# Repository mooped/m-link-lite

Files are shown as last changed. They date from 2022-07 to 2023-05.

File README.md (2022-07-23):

# M-Link Lite

M-Link Lite is a receiver for combat robotics based on the ESP8266 microcontroller. It acts as a WiFi access point and can be controlled from a WebSocket.

M-Link Lite hosts a web server with a basic page for controlling a simple combat robot.

Additional files can be uploaded to control more complex robots with up to 6 channels.

The servo pulsewidth data sent to the WebSocket is passed straight through to the outputs to avoid limiting possibilities.

M-Link Lite has a configurable failsafe so if no updates are received for 500ms the outputs will be put into a safe state.

When turned on M-Link will create a WiFi Access Point named m-link-XXXXXX where XXXXXX is a unique set of digits that identifies the device. The device should be labelled with this ID. A single user can connect to this access point and the controller page should be accessible by navigating to http://m-link-XXXXXXX.local or if wildcard DNS is enabled to any url e.g. http://m-link/ .

When connected to the access point the device will always be available at http://192.168.4.1 . If you are having trouble when using the access point from a mobile device, turning off mobile internet so WiFi is the only option may help.

Once configured via the access point you can enter details for your own access point and the device will connect to it from then on.

## Extending M-Link Lite

The default Drive page on the M-Link Lite device provides a single virtual joystick that directly drives the first two channels. It performs no mixing and is designed for a dual ESC with onboard mixing.

If you wish to use all 6 channels or other features you can upload additional files through the File Manager page that make use of these features.

As a starting point it is recommended to download the default 'Drive' page from [main/joystick.html](main/joystick.html), modify it. You can use the File Manager page on the device to upload and test the modified version.

The on-screen Joystick is implemented with [jeromeetienne/virtualjoystick.js](https://github.com/jeromeetienne/virtualjoystick.js) which has its own documentation and examples for adding additional joysticks.

Some examples are provided for implementing [one](examples/joystick.html), [two](examples/two_stick.html), or [three](examples/three_stick.html) on-screen joysticks in the [examples folder](examples) of the project.

The page talks to the M-Link Lite by sending JSON messages over a websocket and the device will send JSON messages back in response.

The code at line 40 of the Drive page sends an initial packet to center all outputs, and it also sends a set of failsafe values which will be applied if a packet is not received for 500 milliseconds. This is intended to avoid the robot going out of control if the user closes their browser, turns of the controlling device, or the connection is otherwise disrupted.

```
        ws.onopen = function() {
          ws.send(
            JSON.stringify(
              {
                servos: [
                  1500,
                  1500,
                  1500,
                  1500,
                  1500,
                  1500
                ],
                failsafes: [
                  1500,
                  1500,
                  1500,
                  1500,
                  1500,
                  1500
                ],
                query: "settings"
              }
            )
          );
        };
```

The default failsafes will stop a brushed ESC that has a reverse feature and center a servo. If you intend to build a robot using non-reversible ESCs or your servo driven mechanisms require a different position on failsafe you will need to update these values.

The values sent in the `servos` and `failsafes` array are the pulse width that will be sent to the servo in microseconds. 1000 microseconds is usually fully left, 2000 microseconds is fully right, and 1500 microseconds is centered. You can send 0 microseconds to stop sending a signal, which will cause many servos to idle, but depending on the servos you will need to be careful with other out of range values which may cause unexpected behaviour and/or damage.

For the `failsafes` array a value of -1 can be set instead of a pulsewidth to hold the channel at its last position when in failsafe.

The code between lines 103 and 124 is responsible for sending updated values to the M-Link Lite 30 times a second. By altering the values to the `servos` array you can make use of all 6 channels.

```
      setInterval(function(){
        const x = Math.round(joystick.deltaX() * 5);
        const y = Math.round(joystick.deltaY() * 5);
        $msg = JSON.stringify({
          servos: [
            parseInt(1500 - y),
            parseInt(1500 + x),
            1500,
            1500,
            1500,
            1500,
          ]
        });
        if ($('#send').val() != $msg || (++counter % keepalive) === 0) {
          $('#send').val($msg);
          ws.send($msg);
        }

        var outputEl  = document.getElementById('result');
        outputEl.innerHTML = $('#wsresponse').val();

      }, 1/30 * 1000);
```

For example you could declare a second VirtualJoystick instance and have it respond to a second area of the screen, and use it to drive 1 or 2 of the extra channels.

These extensions are likely to depend on the intended features of the robot so the system has designed to leave these up to the user while providing maximum flexibility.

For ease of experimentation the default Drive page declares a `mlink` object in the global scope which contains a reference to the WebSocket. You can use this from the browser's Javascript console to send messages manually.

For example, to request the M-Link device send back the current battery voltage reading:

```
mlink.ws.send(JSON.stringify({
  query: "battery"
});
```

## WebSocket API

The WebSocket API expects a JSON message and responds based on the keys contained in the message.

### Sending servo pulsewidths to drive the robot:

For example Ch 1 center/brake, Ch 2 left/reverse, Ch 3 right/forward, Ch 4 center/brake, Ch 5 left/reverse, Ch 6 right/forward

```
{
  servos: [
    1500,
    1000,
    2000,
    1500,
    1000,
    2000
  ]
}
```

The M-Link will read as many channels from the array as it supports and then ignore any additional values. If fewer values are sent than are supported the remaining channels will be left alone.

### Setting Failsafe Positions

For example Ch 1 center/brake, Ch2 left, Ch3 right, Ch4/5/6 hold position

```
{
  failsafes: [
    1500,
    1000,
    2000,
    -1
    -1
    -1
  ]
}
```

The `failsafes` key is handled in the same way as a `servos` key with the exception that -1 is interpreted as hold position.

### Updating settings

```
{
  settings: {
    name: "My Robot",
    ssid: "my-ssid",
    password: "my-password"
  }
}
```

The settings object can contain any or all of the keys `name`, `ssid`, `password` and the settings relating to any keys provided will be updated upon receipt of the packet.

If the SSID or Password for the WiFi are changed the settings will be saved immediately but the device must be rebooted before they will take effect.

The SSID and Password fields refer to an external Access Point the device will try to connect to. The details for the M-Link's Access Point are fixed and cannot be changed.

### Resetting Settings

```
{
  reset_settings: "sgnittes_teser"
}
```

The `reset_settings` key will cause a reset of all settings to factory defaults as soon as it is received, so long as the value is the string `"reset_settings"` backwards to prevent accidental resets.

### Rebooting

```
{
  reboot: "toober"
}
```

The `reboot` key will cause an immediate reboot of the device so long as the value is the string `"reboot"` backwards, to prevent accidental reboots.

This can be used after updating settings to apply any that require a reboot to take effect.

### Query

The query key can be used to read various values back from the M-Link.

```
{
  query: "battery"
}
```

The device will respond to a `battery` query with an object containing the value read on the ADC which may be connected to an external battery of the 5v rail of the servo connectors depending on the device and how it is wired.

```
{
  query: "failsafes"
}
```

The device will respond to a `failsafes` query with the current failsafe values.

```
{
  query: "settings"
}
```

The device will respond to a `settings` query with an object containing the current settings.

## Safety

M-Link Lite is designed as a simple device to make it easy to get started and because of this it has been designed to be simple and robust at the expense of some security features.

To avoid users locking themselves out of the device its Access Point has a fixed password, and when connected to a shared Access Point there is no authentication to prevent other users from taking control of the device. For this reason we do not recommend using this device for any robot with spinning weapons or any other weapons that would be dangerous if activated unexpectedly.

## Building The Project

This project is based on the ESP8266 FreeRTOS SDK, which is the ESP8266 equivalent of the ESP32's ESP-IDF project.

You can find instructions for installing and setting this up in their [Getting Started Guide](https://docs.espressif.com/projects/esp8266-rtos-sdk/en/latest/get-started/index.html).

This project uses a version of the ESP8266 FreeRTOS SDK that I modified to include the ESP32 version's web server. You will need to check out [my ESP8266_RTOS_SDK_ESP32TTTPD project](https://github.com/mooped/ESP8266_RTOS_SDK_ESP32HTTPD) instead of the official version.

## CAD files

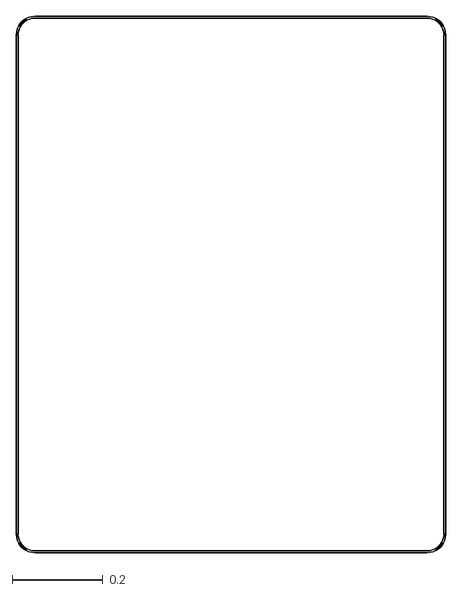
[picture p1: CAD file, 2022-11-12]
hardware/m-link-lite_v1_1_stencil/m-link-lite-Edge_Cuts.dxf
0.949 x 1.19

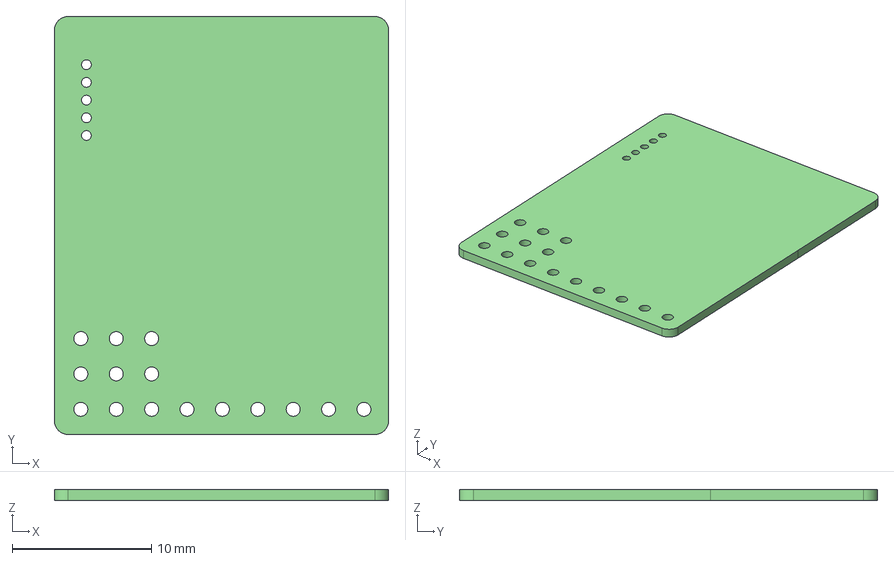
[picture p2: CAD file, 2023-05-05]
hardware_plus/m-link-plus.step
24.0 x 30.0 x 0.791 mm

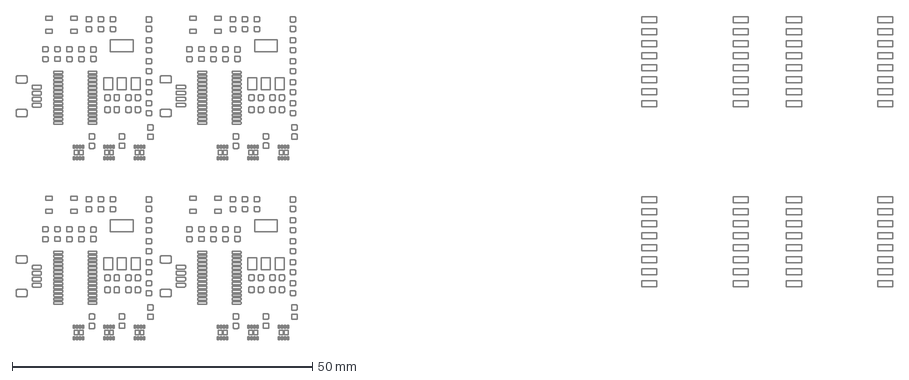
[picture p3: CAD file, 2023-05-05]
hardware_plus/m-link-plus_v1_0_stencil/merged_2x2.dxf
146.1 x 53.9 mm

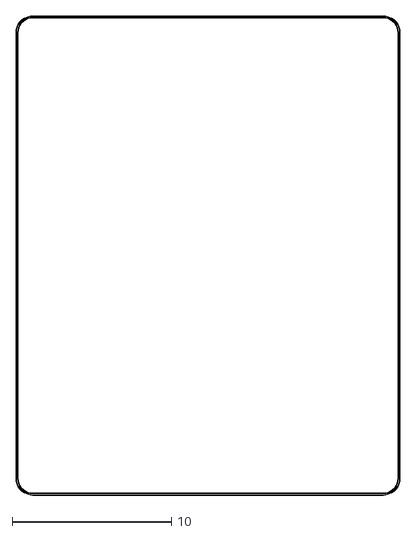
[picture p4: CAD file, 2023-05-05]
hardware_plus/m-link-plus_v1_0_stencil/m-link-plus-Edge_Cuts.dxf
24.1 x 30.1

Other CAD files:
hardware/m-link-lite_v1_1_stencil/m-link-lite-B_Paste.dxf
hardware/m-link-lite_v1_1_stencil/m-link-lite-F_Paste.dxf
hardware_plus/m-link-plus_v1_0_stencil/m-link-plus-B_Paste.dxf
hardware_plus/m-link-plus_v1_0_stencil/m-link-plus-F_Paste.dxf

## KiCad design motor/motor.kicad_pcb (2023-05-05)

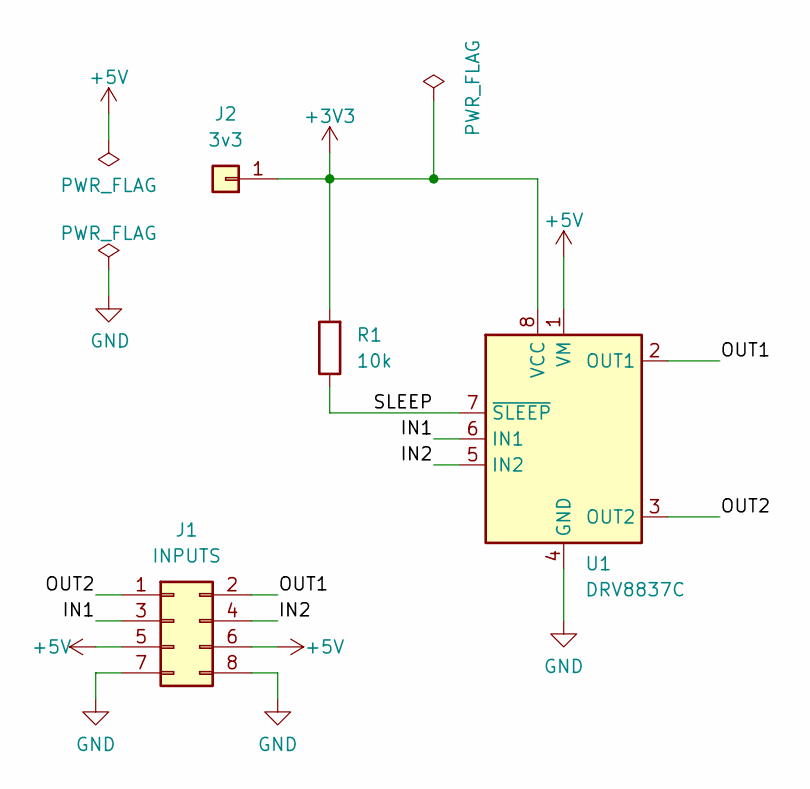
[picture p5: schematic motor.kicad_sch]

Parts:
J1: INPUTS; PinHeader_2x04_P2.54mm_Vertical
J2: 3v3; PinHeader_1x01_P2.54mm_Vertical
R1: 10k; R_0603_1608Metric
U1: DRV8837C; WSON-8-1EP_2x2mm_P0.5mm_EP0.9x1.6mm

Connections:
+3V3: J2.1, R1.2, U1.8 (VCC)
+5V: J1.5, J1.6, U1.1 (VM)
/IN1: J1.3, U1.6 (IN1)
/IN2: J1.4, U1.5 (IN2)
/OUT1: J1.2, U1.2 (OUT1)
/OUT2: J1.1, U1.3 (OUT2)
/SLEEP: R1.1, U1.7 (~SLEEP)
GND: J1.7, J1.8, U1.4 (GND), U1.9 (GND)

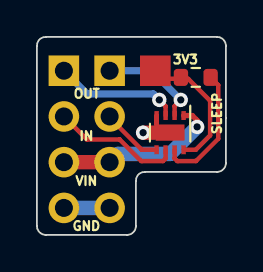
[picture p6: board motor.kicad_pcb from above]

Board: 2 copper layers, 10.5 x 11.0 mm, 4 parts (0 on the bottom side), 8 nets.

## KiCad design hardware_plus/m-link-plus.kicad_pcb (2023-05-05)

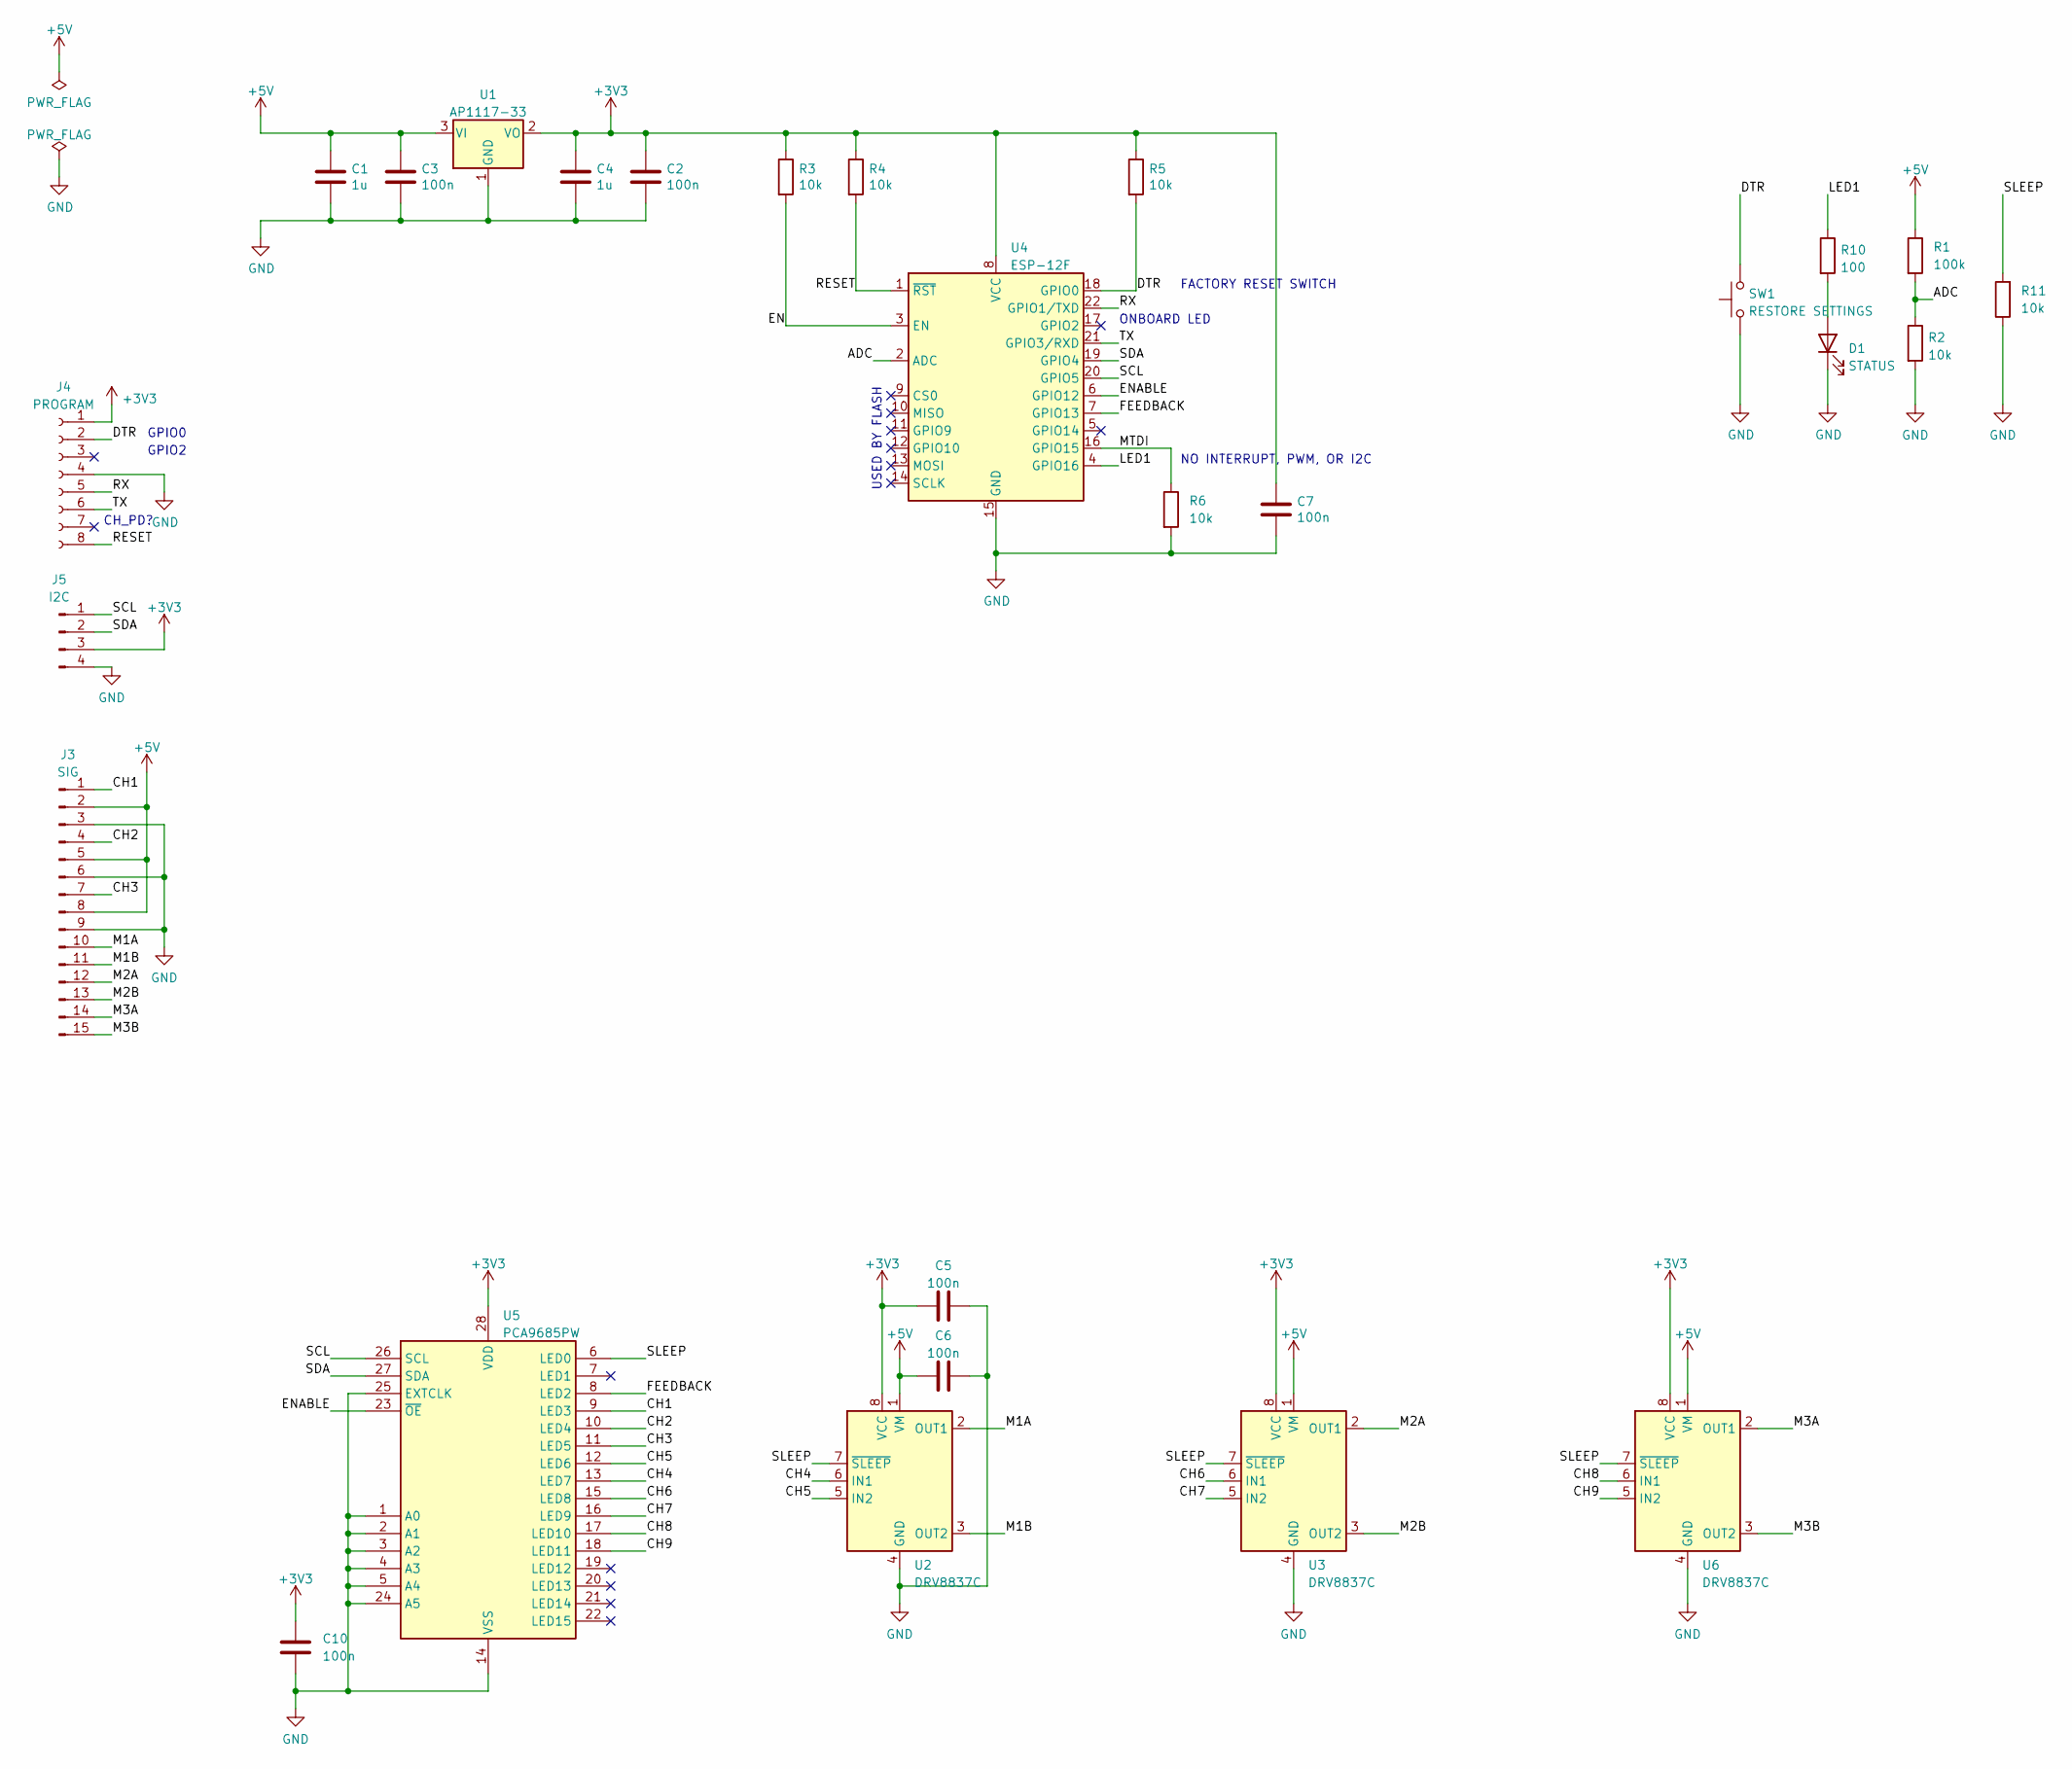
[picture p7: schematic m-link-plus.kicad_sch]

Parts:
C1, C4: 1u; C_0603_1608Metric
C2, C3, C5, C6, C7, C10: 100n; C_0603_1608Metric
D1: STATUS; LED_0603_1608Metric
J3: SIG; ServoHeader_3x06_P2.54mm_Vertical
J4: PROGRAM; SOIC_clipProgSmall
J5: I2C; JST_SH_BM04B-SRSS-TB_1x04-1MP_P1.00mm_Vertical
R1: 100k; R_0603_1608Metric
R2, R3, R4, R5, R6, R11: 10k; R_0603_1608Metric
R10: 100; R_0603_1608Metric
SW1: RESTORE SETTINGS; SW_SPST_PTS810
U1: AP1117-33; SOT-223-3_TabPin2
U2, U3, U6: DRV8837C; WSON-8-1EP_2x2mm_P0.5mm_EP0.9x1.6mm
U4: ESP-12F; ESP-12E
U5: PCA9685PW; TSSOP-28_4.4x9.7mm_P0.65mm

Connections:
+3V3: C2.1, C4.1, C5.1, C7.1, C10.1, J4.1, J5.3, R3.1, R4.1, R5.1, U1.2 (VO), U2.8 (VCC), U3.8 (VCC), U4.8 (VCC), U5.28 (VDD), U6.8 (VCC)
+5V: C1.1, C3.1, C6.1, J3.2, J3.5, J3.8, R1.1, U1.3 (VI), U2.1 (VM), U3.1 (VM), U6.1 (VM)
/ADC: R1.2, R2.1, U4.2 (ADC)
/CH1: J3.1, U5.9 (LED3)
/CH2: J3.4, U5.10 (LED4)
/CH3: J3.7, U5.11 (LED5)
/CH4: U2.6 (IN1), U5.13 (LED7)
/CH5: U2.5 (IN2), U5.12 (LED6)
/CH6: U3.6 (IN1), U5.15 (LED8)
/CH7: U3.5 (IN2), U5.16 (LED9)
/CH8: U5.17 (LED10), U6.6 (IN1)
/CH9: U5.18 (LED11), U6.5 (IN2)
/DTR: J4.2, R5.2, SW1.2, U4.18 (GPIO0)
/EN: R3.2, U4.3 (EN)
/ENABLE: U4.6 (GPIO12), U5.23 (~OE)
/FEEDBACK: U4.7 (GPIO13), U5.8 (LED2)
/LED1: R10.1, U4.4 (GPIO16)
/M1A: J3.10, U2.2 (OUT1)
/M1B: J3.11, U2.3 (OUT2)
/M2A: J3.12, U3.2 (OUT1)
/M2B: J3.13, U3.3 (OUT2)
/M3A: J3.14, U6.2 (OUT1)
/M3B: J3.15, U6.3 (OUT2)
/MTDI: R6.1, U4.16 (GPIO15)
/RESET: J4.8, R4.2, U4.1 (~RST)
/RX: J4.5, U4.22 (GPIO1/TXD)
/SCL: J5.1, U4.20 (GPIO5), U5.26 (SCL)
/SDA: J5.2, U4.19 (GPIO4), U5.27 (SDA)
/SLEEP: R11.2, U2.7 (~SLEEP), U3.7 (~SLEEP), U5.6 (LED0), U6.7 (~SLEEP)
/TX: J4.6, U4.21 (GPIO3/RXD)
GND: C1.2, C2.2, C3.2, C4.2, C5.2, C6.2, C7.2, C10.2, D1.1 (K), J3.3, J3.6, J3.9, J4.4, J5.4, R2.2, R6.2, R11.1, SW1.1, U1.1 (GND), U2.4 (GND), U2.9 (GND), U3.4 (GND), U3.9 (GND), U4.15 (GND), U5.1 (A0), U5.2 (A1), U5.3 (A2), U5.4 (A3), U5.5 (A4), U5.14 (VSS), U5.24 (A5), U5.25 (EXTCLK), U6.4 (GND), U6.9 (GND)
unnamed: D1.2 (A), R10.2

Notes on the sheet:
FACTORY RESET SWITCH
GPIO0
NO INTERRUPT, PWM, OR I2C
CH_PD?
USED BY FLASH
GPIO2
ONBOARD LED

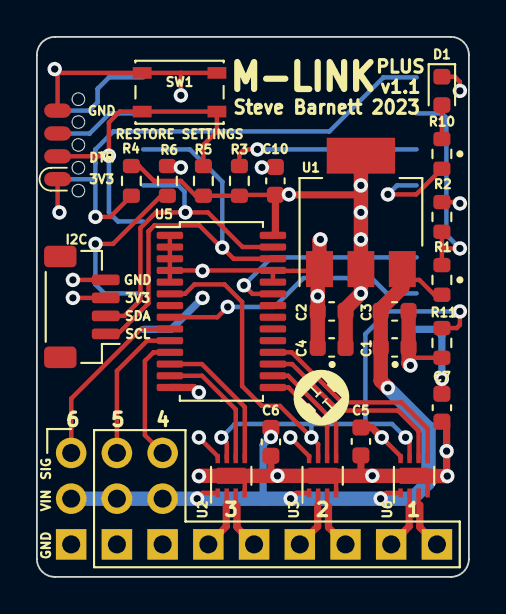
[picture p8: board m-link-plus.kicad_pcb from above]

Board: 4 copper layers, 24.0 x 30.0 mm, 27 parts (1 on the bottom side), 32 nets.

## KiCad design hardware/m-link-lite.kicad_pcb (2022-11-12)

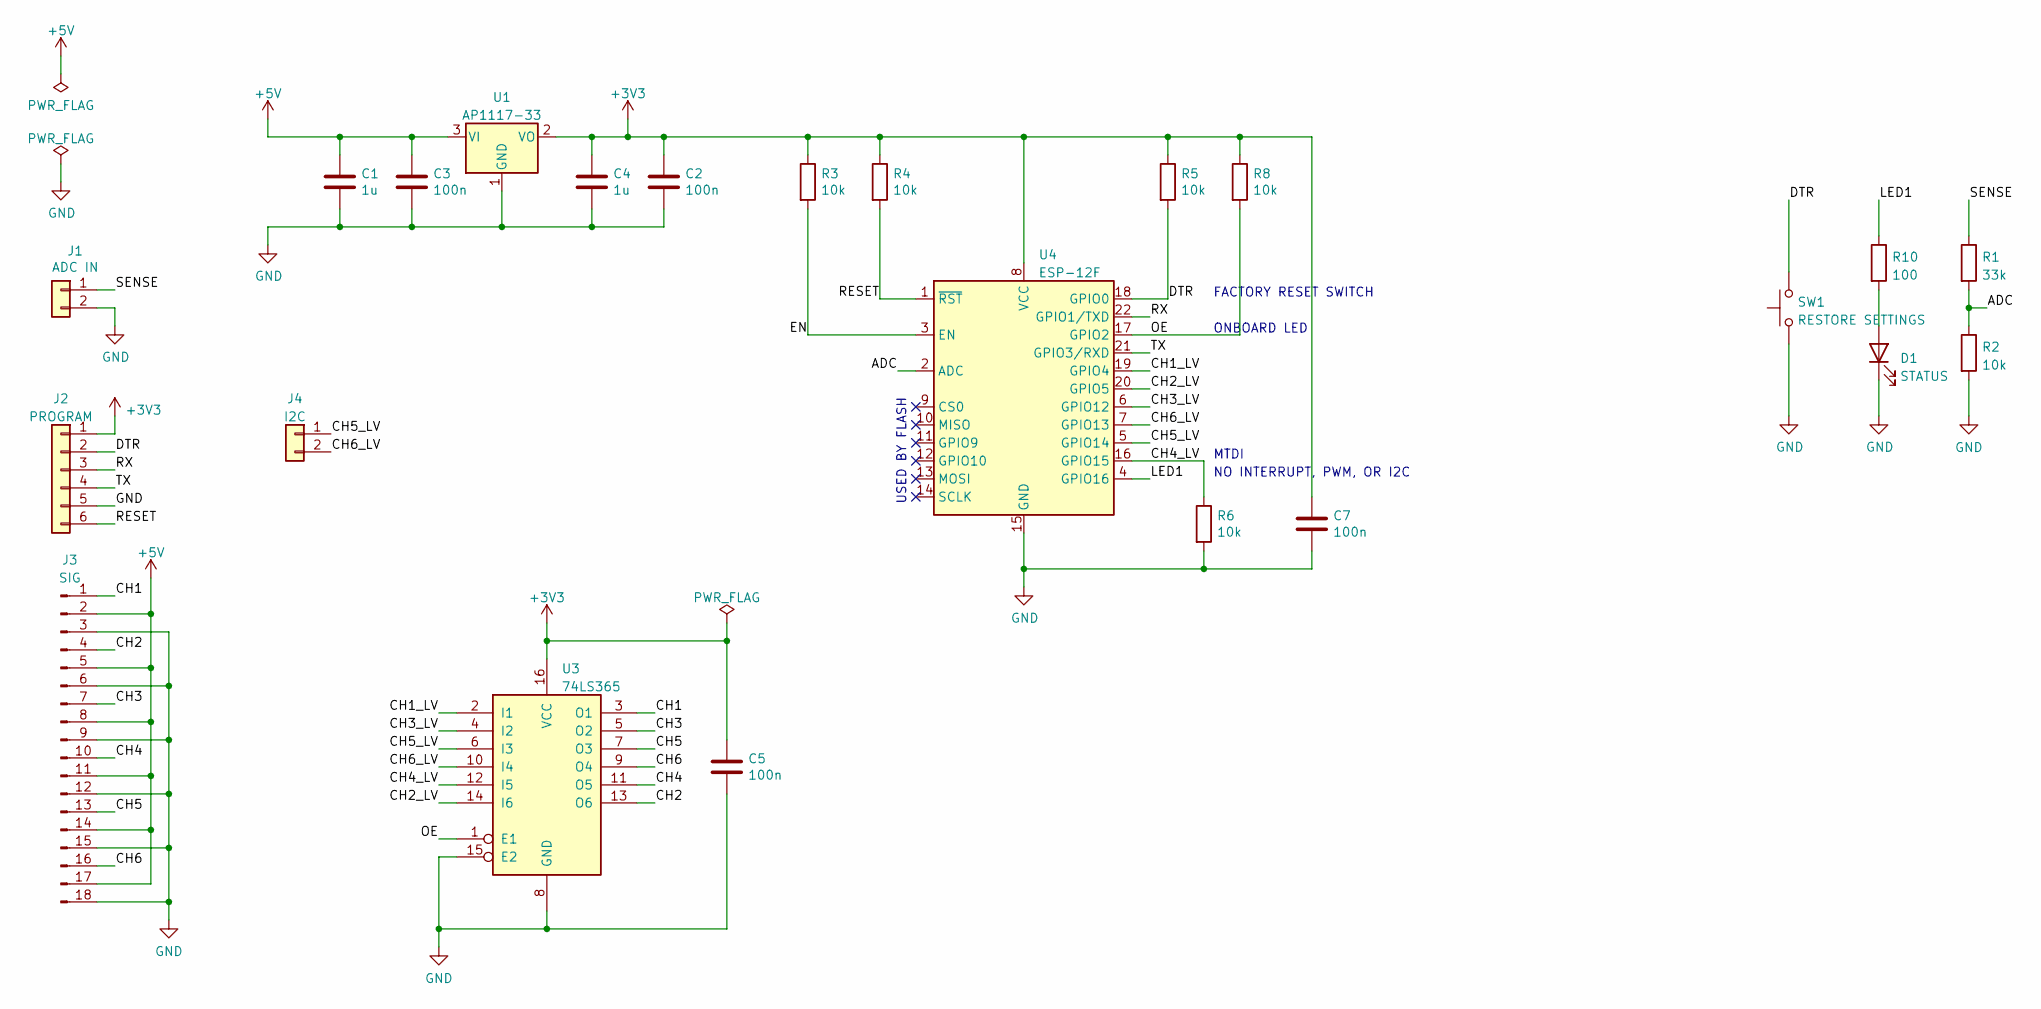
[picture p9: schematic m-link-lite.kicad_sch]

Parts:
C1, C4: 1u; C_0603_1608Metric
C2, C3, C5, C7: 100n; C_0603_1608Metric
D1: STATUS; LED_0603_1608Metric
J1: ADC IN; PinHeader_1x02_P2.54mm_Vertical
J2: PROGRAM; PinHeader_1x06_P2.54mm_Vertical
J3: SIG; ServoHeader_3x06_P2.54mm_Vertical
J4: I2C
R1: 33k; R_0603_1608Metric
R2, R3, R4, R5, R6, R8: 10k; R_0603_1608Metric
R10: 100; R_0603_1608Metric
SW1: RESTORE SETTINGS; SW_SPST_PTS810
U1: AP1117-33; SOT-223-3_TabPin2
U3: 74LS365; SO-16_3.9x9.9mm_P1.27mm
U4: ESP-12F; ESP-12E

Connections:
+3V3: C2.1, C4.1, C5.1, C7.1, J2.1, R3.1, R4.1, R5.1, R8.1, U1.2 (VO), U3.16 (VCC), U4.8 (VCC)
+5V: C1.1, C3.1, J3.2, J3.5, J3.8, J3.11, J3.14, J3.17, U1.3 (VI)
/ADC: R1.2, R2.1, U4.2 (ADC)
/CH1: J3.1, U3.3 (O1)
/CH1_LV: U3.2 (I1), U4.19 (GPIO4)
/CH2: J3.4, U3.13 (O6)
/CH2_LV: U3.14 (I6), U4.20 (GPIO5)
/CH3: J3.7, U3.5 (O2)
/CH3_LV: U3.4 (I2), U4.6 (GPIO12)
/CH4: J3.10, U3.11 (O5)
/CH4_LV: R6.1, U3.12 (I5), U4.16 (GPIO15)
/CH5: J3.13, U3.7 (O3)
/CH5_LV: J4.1, U3.6 (I3), U4.5 (GPIO14)
/CH6: J3.16, U3.9 (O4)
/CH6_LV: J4.2, U3.10 (I4), U4.7 (GPIO13)
/DTR: J2.2, R5.2, SW1.2, U4.18 (GPIO0)
/EN: R3.2, U4.3 (EN)
/LED1: R10.1, U4.4 (GPIO16)
/OE: R8.2, U3.1 (E1), U4.17 (GPIO2)
/RESET: J2.6, R4.2, U4.1 (~RST)
/RX: J2.3, U4.22 (GPIO1/TXD)
/SENSE: J1.1, R1.1
/TX: J2.4, U4.21 (GPIO3/RXD)
GND: C1.2, C2.2, C3.2, C4.2, C5.2, C7.2, D1.1 (K), J1.2, J2.5, J3.3, J3.6, J3.9, J3.12, J3.15, J3.18, R2.2, R6.2, SW1.1, U1.1 (GND), U3.8 (GND), U3.15 (E2), U4.15 (GND)
unnamed: D1.2 (A), R10.2

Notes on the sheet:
FACTORY RESET SWITCH
NO INTERRUPT, PWM, OR I2C
USED BY FLASH
ONBOARD LED
MTDI

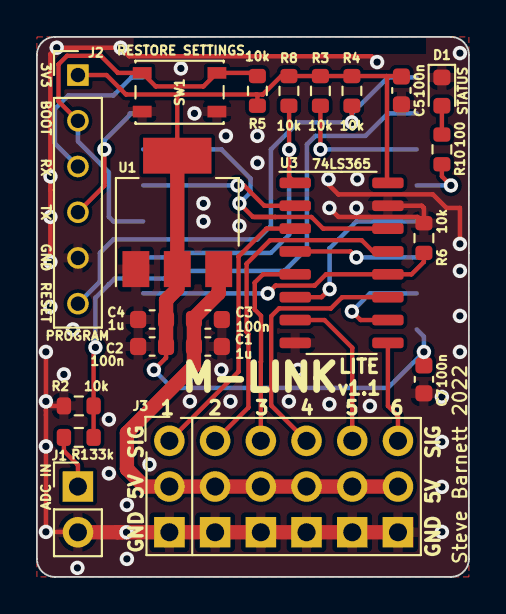
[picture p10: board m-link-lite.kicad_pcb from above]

Board: 2 copper layers, 24.0 x 30.0 mm, 22 parts (1 on the bottom side), 25 nets.

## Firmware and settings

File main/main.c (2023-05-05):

/* M-Link Lite

   A simple receiver/controller for Combat Robotics using WebSockets and a SoftAP access point.
*/

#include <stdio.h>
#include <string.h>
#include <stdlib.h>

#include "freertos/FreeRTOS.h"
#include "freertos/task.h"
#include "freertos/timers.h"
#include "freertos/queue.h"
#include "freertos/semphr.h"

#include "nvs_flash.h"

#include "esp_event.h"
#include "esp_err.h"
#include "esp_log.h"
#include "esp_system.h"

#include <esp_http_server.h>
#include <esp_spiffs.h>
#include <esp_vfs.h>

#include "twi.h"
#include "battery.h"
#include "button.h"
#include "dns.h"
#include "event.h"
#include "led.h"
#include "server.h"
#include "servo.h"
#include "settings.h"
#include "wifi.h"

static const char *TAG = "m-link-lite-main";

#define RX_LED_NUM  1

static led_config_t rx_led_config[RX_LED_NUM] = {
  {
    .timer = NULL,
    .gpio_num = GPIO_NUM_16,
    .period = pdMS_TO_TICKS(2000),
    .duty = pdMS_TO_TICKS(1000),
    .state = 0,
  },
};

typedef enum
{
  RX_LED_WAITING,
  RX_LED_ACTIVE,
  RX_LED_FAILSAFE,
  RX_LED_INITIAL,
}
rx_led_state_t;

rx_led_state_t rx_led_state = RX_LED_INITIAL;

void rx_led_set_state(rx_led_state_t new_state)
{
  if (new_state != rx_led_state)
  {
    switch (new_state)
    {
      case RX_LED_WAITING:
      {
        led_set(0, 1, 1000, 2000);
      } break;
      case RX_LED_ACTIVE:
      {
        led_set(0, 1, 1000, 1000);
      } break;
      case RX_LED_FAILSAFE:
      {
        led_set(0, 1, 100, 500);
      } break;
      default:
      {
        ESP_LOGW(TAG, "Invalid LED state requested.");
      }
    }
    rx_led_state = new_state;
  }
}

static int battery_level = 0;

int query_battery_voltage(void)
{
  return battery_level;
}

void rx_telemetry_task(void* args)
{
  ESP_LOGI(TAG, "Started telemetry task.");

  // Initialise battery voltage and RSSI measurement
  ESP_ERROR_CHECK( battery_init() );

  // Update telemetry once a second
  const TickType_t interval = pdMS_TO_TICKS(1000);
  TickType_t previous_wake_time = xTaskGetTickCount();

  for (;;)
  {
    // Print battery level
    battery_level = battery_get_level();
    //ESP_LOGI(TAG, "Battery Level: %d", battery_level);

    // Wait for the next interval
    vTaskDelayUntil(&previous_wake_time, interval);
  }
}

xTimerHandle rx_failsafe_timer = NULL;
bool failsafe_elapsed = false;

#define SERVO_NUM   6
static int servos[SERVO_NUM] = { 1500, 1500, 1500, 1500, 1500, 1500 };
static int failsafes[SERVO_NUM] = { 1500, 1500, 1500, 1500, 1500, 1500 };

int query_supported_channels(void)
{
  return SERVO_NUM;
}

void process_servo_event(int channel, int pulsewidth_ms)
{
  if (channel >= 0 && channel < SERVO_NUM)
  {
    // Update the channel
    servos[channel] = pulsewidth_ms;
    
    // Reset failsafe
    xTimerReset(rx_failsafe_timer, 0);
    if (failsafe_elapsed)
    {
      // Log the first time we reset
      ESP_LOGW(TAG, "Failsafe disengaged.");

      // Set LED state to active
      rx_led_set_state(RX_LED_ACTIVE);
    }
    failsafe_elapsed = false;
  }
  else
  {
    ESP_LOGW(TAG, "Ignoring request to set out of range servo %d to %d ms.", channel, pulsewidth_ms);
  }
}

void process_failsafe_event(int channel, int pulsewidth_ms)
{
  if (channel >= 0 && channel < SERVO_NUM)
  {
    // Update the failsafe
    failsafes[channel] = pulsewidth_ms;
  }
  else
  {
    ESP_LOGW(TAG, "Ignoring request to set out of range failsafe value %d to %d ms.", channel, pulsewidth_ms);
  }
}

int query_failsafe(int channel)
{
  if (channel >= 0 && channel < SERVO_NUM)
  {
    // Update the failsafe
    return failsafes[channel];
  }
  else
  {
    ESP_LOGW(TAG, "Ignoring request to query of range failsafe value %d.", channel);
    return -1;
  }
}

bool query_failsafe_engaged(void)
{
    return failsafe_elapsed;
}

void rx_failsafe_callback(xTimerHandle xTimer)
{
  // Print a message when failsafe elapses
  if (!failsafe_elapsed)
  {
    ESP_LOGW(TAG, "Failsafe engaged - send an update to disengage!");

    // Set LED to indicate failsafe
    rx_led_set_state(RX_LED_FAILSAFE);
  }

  // Stop servo updates from rx_task
  failsafe_elapsed = true;

  // Set failsafe values to the servos
  for (int channel = 0; channel < SERVO_NUM; ++channel)
  {
    // Negative failsafe values indicate that the channel should be held
    // Positive values are the pulsewidth to set
    if (failsafes[channel] >= 0)
    {
      servo_set(channel, failsafes[channel]);
    }
  }
}

void rx_task(void* args)
{
  ESP_LOGI(TAG, "Started rx task");

  // Wait 2 seconds on startup before enabling the servos
  vTaskDelay(pdMS_TO_TICKS(2000));

  ESP_LOGI(TAG, "Enable servos");
  servo_enable();

  // Update servos every 20 ms
  const TickType_t interval = pdMS_TO_TICKS(20);
  TickType_t previous_wake_time = xTaskGetTickCount();

  for (;;)
  {
    if (!failsafe_elapsed)
    {
      // Update the servo driver if not in failsafe mode
      for (int channel = 0; channel < SERVO_NUM; ++channel)
      {
        servo_set(channel, servos[channel]);
      }
    }

    // Wait for the next interval
    vTaskDelayUntil(&previous_wake_time, interval);
  }
}

void app_main()
{
#if 1
  // Initialise I2C driver
  ESP_ERROR_CHECK( twi_init() );
#endif

  // Initialise and immediately disable servo module as soon as possible to avoid glitches
  servo_init();
  servo_disable();

  // Initialize NVS
  esp_err_t err = nvs_flash_init();
  if (err == ESP_ERR_NVS_NO_FREE_PAGES || err == ESP_ERR_NVS_NEW_VERSION_FOUND)
  {
    ESP_LOGW(TAG, "Failed to initialise NVS, erasing to reinitialise.");
    // If we can't initialise NVS, erase and recreate the partition
    ESP_ERROR_CHECK( nvs_flash_erase() );
    err = nvs_flash_init();
  }
  ESP_ERROR_CHECK(err);

  // Initialise settings
  settings_init();

  // Set LED to boot state (2 second flash)
  ESP_ERROR_CHECK( led_init(rx_led_config, RX_LED_NUM) );
  rx_led_set_state(RX_LED_WAITING);

  // Initialise button handler
  button_init();

  // Create event loop
  ESP_ERROR_CHECK(esp_event_loop_create_default());

  // Initialise WiFi
  wifi_init_apsta();

  // Start the webserver
  server_init();

  // Initialise RX task
  xTaskCreate(rx_task, "rx-task", 2048, NULL, 10, NULL);

  // Initialise RX telemetry task
  xTaskCreate(rx_telemetry_task, "rx-telemetry-task", 2048, NULL, 7, NULL);

  // Initialise mDNS
  mlink_dns_init();

  // Start failsafe timer
  rx_failsafe_timer = xTimerCreate("rx-failsafe-timer", pdMS_TO_TICKS(500), pdTRUE, NULL, rx_failsafe_callback);
  xTimerStart(rx_failsafe_timer, 0);
}

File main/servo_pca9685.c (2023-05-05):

#include <stdio.h>
#include <string.h>
#include <stdlib.h>
#include <limits.h>

#include "freertos/FreeRTOS.h"
#include "freertos/semphr.h"
#include "freertos/task.h"
#include "freertos/timers.h"

#include "esp_log.h"
#include "esp_system.h"
#include "esp_err.h"

#include "esp8266/gpio_register.h"
#include "esp8266/pin_mux_register.h"

#include "driver/gpio.h"
#include "driver/pwm.h"

#include "pca9685.h"

#include "servo.h"

#if 1

#define ENABLE_IO_NUM             12
#define FEEDBACK_IO_NUM           13

#define PCA9685_CHANNEL_SLEEP     0
#define PCA9685_CHANNEL_FEEDBACK  2
#define PCA9685_CHANNEL_M1A       11
#define PCA9685_CHANNEL_M1B       10
#define PCA9685_CHANNEL_M2A       9
#define PCA9685_CHANNEL_M2B       8
#define PCA9685_CHANNEL_M3A       7
#define PCA9685_CHANNEL_M3B       6
#define PCA9685_CHANNEL_CH4       5
#define PCA9685_CHANNEL_CH5       4
#define PCA9685_CHANNEL_CH6       3

#define SERVO_NUM_CHANNELS        9

static const char *TAG = "pca9685-servo";

static uint32_t pulsewidths[SERVO_NUM_CHANNELS] = {
  1500, 1500, 1500, 1500, 1500, 1500,
};

static SemaphoreHandle_t xServoSemaphore = NULL;

void servo_enable(void)
{
  // Set enable low
  ESP_ERROR_CHECK( gpio_set_level(ENABLE_IO_NUM, 0) );
}

void servo_disable(void)
{
  // Set enable high
  ESP_ERROR_CHECK( gpio_set_level(ENABLE_IO_NUM, 1) );
}

void servo_set(int channel, int pulsewidth_ms)
{
  if (channel >= 0 && channel < SERVO_NUM_CHANNELS)
  {
    // Store pulsewidth for the channel
    if (pulsewidth_ms <= 1000)
    {
      pulsewidths[channel] = 1000;
    }
    else if (pulsewidth_ms >= 2000)
    {
      pulsewidths[channel] = 2000;
    }
    else
    {
      pulsewidths[channel] = pulsewidth_ms;
    }
  }
}

static void motor_set(int channel_a, int channel_b, int pulsewidth)
{
  if (pulsewidth < 1000 || pulsewidth > 2000) // Coast
  {
    pca9685_set_off(channel_a);
    pca9685_set_off(channel_b);
  }
  else if (pulsewidth == 1500) // Brake
  {
    pca9685_set_on(channel_a);
    pca9685_set_on(channel_b);
  }
  else if (pulsewidth > 1500) // Forward
  {
    pca9685_set_off(channel_a);
    pca9685_set_raw(channel_b, ((pulsewidth - 1500) * 4095) / 500); // Scale from 0 - 500 to 0 - 4095
  }
  else if (pulsewidth < 1500) // Reverse
  {
    pca9685_set_raw(channel_a, ((1500 - pulsewidth) * 4095) / 500); // Scale from 0 - 500 to 0 - 4095
    pca9685_set_off(channel_b);
  }
}

void servo_set_all(int s1, int s2, int s3, int s4, int s5, int s6)
{
  servo_set(0, s1);
  servo_set(1, s2);
  servo_set(2, s3);
  servo_set(3, s4);
  servo_set(4, s5);
  servo_set(5, s6);
}

static void feedback_isr_handler(void* arg)
{
  // Wake up and yield to the servo task at the start of each frame
  BaseType_t xHigherPriorityTaskWoken = pdFALSE;
  xSemaphoreGiveFromISR(xServoSemaphore, &xHigherPriorityTaskWoken);
  if (xHigherPriorityTaskWoken == pdTRUE)
  {
    portYIELD_FROM_ISR();
  }
}

void servo_task(void* args)
{
  ESP_LOGI(TAG, "Started servo task");

  // Enable feedback pulse
  pca9685_set_microseconds(PCA9685_CHANNEL_FEEDBACK, 1500);

  for (;;)
  {
    // Output pulse to first servo channel
    //xSemaphoreTake(xServoSemaphore, portMAX_DELAY);
    //pca9685_set_microseconds(PCA9685_CHANNEL_CH4, pulsewidths[3]);
    //xSemaphoreTake(xServoSemaphore, portMAX_DELAY);
    //pca9685_set_off(PCA9685_CHANNEL_CH4);

    // Output pulse to second servo channel
    //xSemaphoreTake(xServoSemaphore, portMAX_DELAY);
    //pca9685_set_microseconds(PCA9685_CHANNEL_CH5, pulsewidths[4]);
    //xSemaphoreTake(xServoSemaphore, portMAX_DELAY);
    //pca9685_set_off(PCA9685_CHANNEL_CH5);

    // Output pulse to third servo channel
    //xSemaphoreTake(xServoSemaphore, portMAX_DELAY);
    //pca9685_set_microseconds(PCA9685_CHANNEL_CH6, pulsewidths[5]);
    //xSemaphoreTake(xServoSemaphore, portMAX_DELAY);
    //pca9685_set_off(PCA9685_CHANNEL_CH6);

    // Update motor channels on the next sync pulse
    //xSemaphoreTake(xServoSemaphore, portMAX_DELAY);
    motor_set(PCA9685_CHANNEL_M1A, PCA9685_CHANNEL_M1B, pulsewidths[0]);
    motor_set(PCA9685_CHANNEL_M2A, PCA9685_CHANNEL_M2B, pulsewidths[1]);
    motor_set(PCA9685_CHANNEL_M3A, PCA9685_CHANNEL_M3B, pulsewidths[2]);

    vTaskDelay(20 / portTICK_PERIOD_MS);

    // Three more sync pulses for a period of about 20ms
    //xSemaphoreTake(xServoSemaphore, portMAX_DELAY);
    //xSemaphoreTake(xServoSemaphore, portMAX_DELAY);
    //xSemaphoreTake(xServoSemaphore, portMAX_DELAY);
  }
}

void servo_init(void)
{
  // Create the semaphore
  xServoSemaphore = xSemaphoreCreateBinary();

  // Initialize the PCA 9685
  pca9685_initialize();

  // Configure the enable pin and pull high to disable
  gpio_config_t config;
  config.pin_bit_mask = (1ull<<(ENABLE_IO_NUM));
  config.mode = GPIO_MODE_OUTPUT;
  config.pull_up_en = GPIO_PULLUP_DISABLE;
  config.pull_down_en = GPIO_PULLDOWN_DISABLE;
  config.intr_type = GPIO_INTR_DISABLE;
  ESP_ERROR_CHECK( gpio_config(&config) );
  ESP_ERROR_CHECK( gpio_set_level(ENABLE_IO_NUM, 1) );

  // Configure feedback pin and interrupt to detect PPM frame start
  config.pin_bit_mask = (1ull<<(FEEDBACK_IO_NUM));
  config.mode = GPIO_MODE_INPUT;
  config.pull_up_en = GPIO_PULLUP_DISABLE;
  config.pull_down_en = GPIO_PULLDOWN_DISABLE;
  config.intr_type = GPIO_INTR_POSEDGE;
  ESP_ERROR_CHECK( gpio_config(&config) );
  ESP_ERROR_CHECK( gpio_install_isr_service(0) );
  ESP_ERROR_CHECK( gpio_isr_handler_add(FEEDBACK_IO_NUM, feedback_isr_handler, (void*)FEEDBACK_IO_NUM) );
  ESP_ERROR_CHECK( gpio_config(&config) );

  // Configure the sleep pin on the PCA9685 high to disable sleep when outputs are enabled
  pca9685_set_all_off();
  pca9685_set_on(PCA9685_CHANNEL_SLEEP);

  ESP_LOGI(TAG, "PCA9685 Initialised");
  xTaskCreate(servo_task, "servo-task", 2048, NULL, 11, NULL);
}

#endif

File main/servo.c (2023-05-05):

#include <stdio.h>
#include <string.h>
#include <stdlib.h>

#include "freertos/FreeRTOS.h"

#include "esp_log.h"
#include "esp_system.h"
#include "esp_err.h"

#include "esp8266/gpio_register.h"
#include "esp8266/pin_mux_register.h"

#include "driver/gpio.h"
#include "driver/pwm.h"

#include "servo.h"

#if 0

#define PWM_IO_COUNT      6

#define ENABLE_IO_NUM     2

#define PWM_0_OUT_IO_NUM  4   // Servo 1
#define PWM_1_OUT_IO_NUM  5   // Servo 2
#define PWM_2_OUT_IO_NUM  12  // Servo 3
#define PWM_3_OUT_IO_NUM  15  // Servo 4
#define PWM_4_OUT_IO_NUM  14  // Servo 5
#define PWM_5_OUT_IO_NUM  13  // Servo 6

// PWM period 20ms (50hz)
#define PWM_PERIOD    (20000)

static const char *TAG = "m-link-servo";

// pwm pin number
static const uint32_t pin_num[PWM_IO_COUNT] = {
  PWM_0_OUT_IO_NUM,
  PWM_1_OUT_IO_NUM,
  PWM_2_OUT_IO_NUM,
  PWM_3_OUT_IO_NUM,
  PWM_4_OUT_IO_NUM,
  PWM_5_OUT_IO_NUM,
};

// duties table, real_duty = duties[x]/PERIOD
static uint32_t duties[PWM_IO_COUNT] = {
  1500, 1500, 1500, 1500, 1500, 1500,
};

// phase table, delay = (phase[x]/360)*PERIOD
static float phase[PWM_IO_COUNT] = {
  0.f, 0.f, 0.f, 0.f, 0.f, 0.f,
};

void servo_init(void)
{
  ESP_ERROR_CHECK( pwm_init(PWM_PERIOD, duties, PWM_IO_COUNT, pin_num) );
  ESP_ERROR_CHECK( pwm_set_phases(phase) );
  ESP_ERROR_CHECK( pwm_start() );

  gpio_config_t config;
  config.pin_bit_mask = (1ull<<(ENABLE_IO_NUM));
  config.mode = GPIO_MODE_OUTPUT;
  config.pull_up_en = GPIO_PULLUP_DISABLE;
  config.pull_down_en = GPIO_PULLDOWN_DISABLE;
  config.intr_type = GPIO_INTR_DISABLE;
  ESP_ERROR_CHECK( gpio_config(&config) );
  ESP_ERROR_CHECK( gpio_set_level(ENABLE_IO_NUM, 1) );
}

void servo_enable(void)
{
  ESP_ERROR_CHECK( gpio_set_level(ENABLE_IO_NUM, 0) );
}

void servo_disable(void)
{
  ESP_ERROR_CHECK( gpio_set_level(ENABLE_IO_NUM, 1) );
}

void servo_set(int channel, int pulsewidth_ms)
{
  if (pulsewidth_ms <= 1000)
  {
    duties[channel] = 1000;
  }
  else if (pulsewidth_ms >= 2000)
  {
    duties[channel] = 2000;
  }
  else
  {
    duties[channel] = pulsewidth_ms;
  }
}

void servo_refresh(void)
{
  pwm_set_duties(duties);
  pwm_start();
}

void servo_set_all(int s1, int s2, int s3, int s4, int s5, int s6)
{
  servo_set(0, s1);
  servo_set(1, s2);
  servo_set(2, s3);
  servo_set(3, s4);
  servo_set(4, s5);
  servo_set(5, s6);

  servo_refresh();
}

#endif

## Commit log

2022-03-28 Initial commit - interface for PWM, and start of an interface for ESPNOW.
2022-03-29 Readme with flow charts for the TX and RX. Tidy up ESPNOW code to keep it self contained.
2022-03-31 Rework to extract recv and send callbacks.
    [main.c]
2022-04-02 Refactoring to support combined RX/TX source. PWM for TX LEDS. Initial work on PPM for the TX.
2022-04-03 Rework directory structure. Low resolution PPM decode using hw_timer interrupt to increment a counter every 50us.
    [main.c, rx-pwm.c, tx-ppm.c]
2022-04-03 Update readme. Working transmission of control data (currently broadcast only).
2022-04-03 Implement brakes on channels 6, 7, and 8.
2022-04-07 Add a timer to the RX to determine when to enter bind mode.
2022-04-07 Ignore messages received before control task queue is allocated. Remove receiver bind mode for now to avoid messing around with writing to Flash.
    [main.c]
2022-04-09 Reimplement bind mode. Move LED control to its own driver using a software timer to reduce PWM cost.
2022-04-09 Rework LED driver with data driven config so the code can be common between TX and RX.
    [led.c, main.c]
2022-04-09 LED driver special case for solid on/off to save using timers. Rework RX LED management. Ignore control updates during binding.
    [led.c, main.c]
2022-04-10 Implement TX LED states. Create a driver to read battery voltage via ADC.
2022-04-10 Basic telemetry layout. Tweak font to add uppercase letters as placeholders for lower case.
2022-04-10 Add battery and antenna glyphs.
2022-04-10 Rework telemetry display. 1 line for RX, 1 line for TX, 1 line for RX mac, 1 spare line.
    [main.c]
2022-04-13 Disable motors as early as possible. Optimise and remove logs. Remove unused tw-pwm module.
2022-04-13 Rename rx-pwm module to motor (pwm clashes with ESP8266 pwm driver).
2022-04-13 Rework PPM interpretation on receiver. Add deadzone and change brake controls to select between brake or coast in deadzone. Enable PPM debug output driven by bind switch.
    [main.c]
2022-04-15 Remove smoothing but improve PPM decode quality by ignoring rollover and blocking non-essential tasks during the critical part of the frame.
2022-04-21 Refactor to double buffer PPM data. Add usitwislave submodule to track where the files from that repo came from.
2022-04-23 Rework PPM capture by actively timing the gaps for error detection.
    [main.c]
2022-04-27 Fix PWM period to allow driving the motors at full power.
2022-07-07 Drive servo outputs and remove m-link code to be replaced with WiFi.
    [main.c, servo.c]
2022-07-12 Working webserver in STA mode for M-Link Lite.
    [partitions.csv]
2022-07-15 Generate pulsewidths in Javascript and pass straight to servo driver.
2022-07-16 Fix memory leak from not freeing cJSON objects.
    [server.c]
2022-07-16 Implement user configurable failsafe.
    [main.c, server.c, servo.c]
2022-07-16 Tweak LED states for failsafe.
    [main.c]
2022-07-16 Rework file handling so essential pages are baked in to Flash. File manager is at /files/ and handles SPIFFS file management.
    [partitions.csv]
2022-07-17 Tidy up and remove unused source files. Add schematics and PCB files for v1.0 board.
    [m-link-lite.kicad_pcb, m-link-lite.kicad_sch]
2022-07-17 Rework settings UI to work via websockets. Implement query interface for settings, failsafes, battery telemetry.
    [main.c, server.c]
2022-07-17 Send failsafes and battery voltage as strings to workaround cJSON issues.
    [server.c]
2022-07-17 Rework and fix APSTA failure handling.
    [main.c]
2022-07-17 Fallback to AP only if no STA SSID is configured. Allow rebooting from Settings page. Show AP SSID on settings page (read only).
    [main.c, server.c]
2022-08-13 Simple servo tester example. Update m-link.js to allow querying the number of channels (for forwards compatibility).
2022-08-13 Support for triggering servos at half time and sound effects (if provided).
2022-08-13 Embed m-link.js into Flash and update embedded scripts. Streamline embedded file serving. Tweak arena.html to avoid hitting the failsafe.
    [server.c]
2022-08-16 Flipper example with a button.
2022-08-16 Tweak flipper button dimensions.
2022-11-12 Power supply rework.
    [m-link-lite.kicad_pcb, m-link-lite.kicad_sch]
2022-11-12 Rework v1.2 layout.
    [m-link-lite.kicad_pcb, m-link-lite.kicad_sch]
2022-11-12 Rotate regulator 180.
    [m-link-lite.kicad_pcb]
2022-11-12 Tidy up.
    [m-link-lite.kicad_pcb]
2022-11-12 Layout tweaks.
    [m-link-lite.kicad_pcb]
2022-11-12 Plot v1.1.
    [m-link-lite.kicad_pcb]
2022-11-12 Hardware v1.1 as manufactured.
    [m-link-lite-B_Cu.gbr, m-link-lite-B_Mask.gbr, m-link-lite-B_Paste.gbr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]
2022-11-12 Add stencil DXFs.
    [m-link-lite-B_Paste.dxf, m-link-lite-Edge_Cuts.dxf, m-link-lite-F_Paste.dxf]
2022-11-12 Implement button handler and support settings reset on 10 second hold.
    [button.c, main.c]
2023-05-02 Implement settings for the local AP SSID/hostname and password. Support default password generated from MAC address or a fixed string.
    [server.c]
2023-05-05 Implement an early out when a packet is only updating servo outputs.
2023-05-05 Add 'plus' version of the hardware with 3 built in motor drivers and 3 servo outputs.
    [m-link-plus.kicad_pcb, m-link-plus.kicad_sch]
2023-05-05 Rework M-Link Plus by swapping the PCA9865 and the regulator.
    [m-link-plus.kicad_pcb, m-link-plus.kicad_sch]
2023-05-05 Add resistors back to GPIO2 and GPIO15.
    [m-link-plus.kicad_pcb, m-link-plus.kicad_sch]
2023-05-05 Plot M-Link Plus v1.0
    [m-link-plus.kicad_pcb, m-link-plus.kicad_sch]
2023-05-05 Improve ground plane.
    [m-link-plus.kicad_pcb]
2023-05-05 M-Link plus gerbers and stencil files.
    [m-link-plus-B_Paste.dxf, m-link-plus-Edge_Cuts.dxf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]
2023-05-05 Tidy up fab layer.
    [m-link-plus.kicad_pcb]
2023-05-05 Implement basic support for the Plus version of the hardware.
    [m-link-plus.kicad_pcb]
2023-05-05 Increase PWM frequency to 483Hz for motors and actively disable after a single cycle to drive the servos. Really needs feedback to an IO to sync with the PCA9685 clock to avoid missing servo PWM cycl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
    [main.c, pca9685.c, servo_pca9685.c]
2023-05-05 Implement feedback path from PCA9865 to an ESP8266 input for timing.
    [m-link-plus.kicad_pcb, m-link-plus.kicad_sch]
2023-05-05 Remove unnecessary resistors and begin improving layout.
    [m-link-plus.kicad_pcb, m-link-plus.kicad_sch]
2023-05-05 Move feedback pin on the pca9685 to be adjacent to the servos.
    [m-link-plus.kicad_pcb, m-link-plus.kicad_sch]
2023-05-05 Backport servo output support from M-Link base firmware. Add interactive HTML BOM for both boards.
    [m-link-plus.kicad_pcb]
2023-05-05 Tidy up plus layout. Add plus HTML BOM.
    [m-link-plus-B_Cu.gbr, m-link-plus-B_Mask.gbr, m-link-plus-B_Paste.gbr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]
2023-05-05 Version 1.1 ready for manufacture.
    [m-link-plus-B_Cu.gbr, m-link-plus-B_Mask.gbr, m-link-plus-B_Paste.gbr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]
2023-05-05 Add a daughterboard with an extra DRV8837 to drive a fourth motor.
    [motor-B_Cu.gbr, motor-B_Mask.gbr, motor-B_Paste.gbr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]
2023-05-05 Support for M-Link Plus v1.1 board.
2023-05-05 Disable servo output as it is causing huge latency.
